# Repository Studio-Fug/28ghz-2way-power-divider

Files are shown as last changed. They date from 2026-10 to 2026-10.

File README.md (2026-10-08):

# 28 GHz two-way power divider / combiner

Experimental YAPNR inverse-designed microstrip Wilkinson coupon targeting the Knowles PDW07630's 24–32 GHz small-signal performance. **Revision A fails the return-loss and loss requirements in exported-footprint simulation. It is not a validated replacement for PDW07630.**

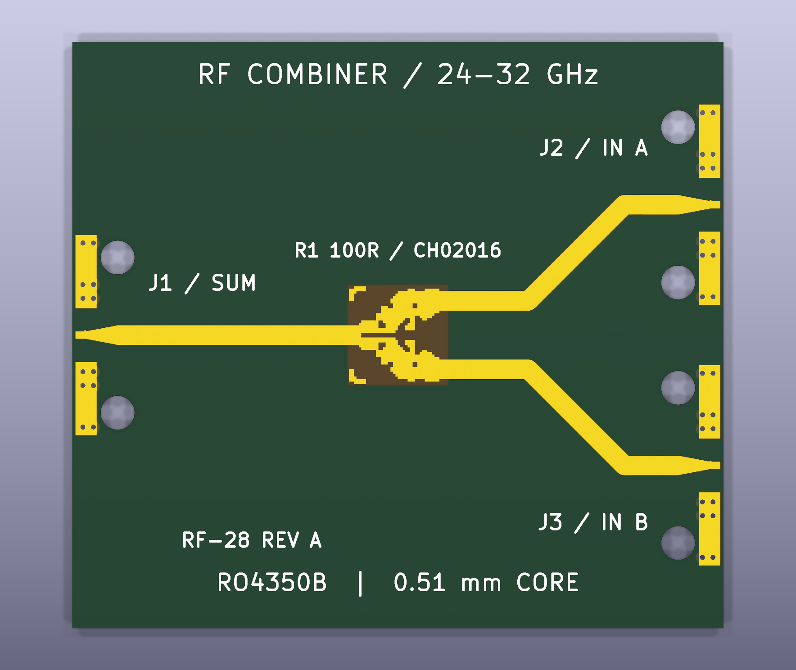
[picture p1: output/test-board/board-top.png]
Revision A test board, bare PCB with edge-launch footprints


The 40 × 36 mm board uses a 0.51 mm RO4350B core, three Southwest Microwave 1092-03A-6 2.92 mm edge launches, equal-length output feeds and a 100 ohm Vishay CH02016 resistor. J1 is SUM, J2/J3 are the two inputs/outputs. The board shot is a KiCad render of the actual copper and mechanical lands; connectors and resistor are not installed in the render.

- [Requirements model](requirements/model.yaml): 3 user needs, 15 requirements and 6 verification methods.
- [Validation report](reports/validation.md): acceptance criteria, grid comparison and links to simulation results.
- [rules_requirements traceability](reports/traceability.md), [HTML](reports/traceability.html), [JSON](reports/traceability.json), [gap queue](reports/gaps.json).
- [KiCad PCB](output/test-board/rf-combiner-test.kicad_pcb), [project](output/test-board/rf-combiner-test.kicad_pro), [BOM](output/test-board/BOM.csv).
- [Fabrication ZIP](output/test-board/rf-combiner-revA-fabrication.zip), [fabrication/assembly notes](FABRICATION.md). Layout DRC passes; RF acceptance does not.
- [Exported RF footprint](runs/jlc20mil/footprint.kicad_mod), [simulation metrics](runs/jlc20mil/comparison.json), [artifact hashes](reports/artifact-manifest.json).

## Requirements and sources

The baseline is the [Knowles datasheet](https://www.knowlescapacitors.com/getattachment/Products/Microwave-Products/Power-Dividers/PDW07630_DATASHEET.pdf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), preserved as [reference PDF](reference/PDW07630_DATASHEET.pdf): 24–32 GHz, return loss ≥15 dB, isolation ≥14 dB, excess insertion loss ≤0.7 dB, amplitude balance ±0.5 dB, phase balance ±5°. The combiner is specified for equal-amplitude, equal-phase inputs. Its 5 W combining rating is not qualified for this coupon.

The workflow follows [YAPNR RF inverse design](https://studio-fug.github.io/yapnr/docs/rf-inverse-design.html). The user's final stackup selection superseded the earlier 10 mil option: **0.51 mm core and 2.92 mm launches**. A larger board footprint was accepted. [DUT optimization spec](specs/dut-optimization.json) holds stricter optimization goals (20 dB return loss, 17 dB isolation, 0.5 dB excess loss); [requirements/model.yaml](requirements/model.yaml) retains the datasheet minimum acceptance thresholds.

## Whole-assembly validation gate

[spec.json](spec.json) is the authoritative project specification. It requires simulation of the complete populated assembly at the three 2.92 mm coaxial mating planes, including the actual feed bends, launch transitions, connectors, ground/vias, finite board, material losses and resistor package. All assembly RF limits include fixture losses. DUT-only simulation and DRC cannot satisfy this gate. One YAPNR-owned assembly SSoT must drive all backend adapters, with common geometry, materials, component mappings and reference planes; client projects supply declarative design/requirements data and must not write custom solver-model or mesh code.

**Assembly simulation is BLOCKED, not completed.** [Readiness report](reports/assembly-validation.json) records missing qualified connector/material models, resistor reference-plane qualification and a supported full-assembly SSoT/adapter workflow. YAPNR does provide suitable openEMS/PALACE engines and partial KiCad/mesh/config integration; the gap is the end-to-end minimal-code assembly path ([issue #97](https://github.com/Studio-Fug/yapnr/issues/97)). The [importer audit](reports/backend-capability-audit.json) also found omitted floating copper and NPTH geometry errors. A [Vishay 100 ohm candidate model](models/resistor/CH02016F_P_100R.s2p) is included, with [provenance](models/resistor/provenance.json); it has 100 ohm normalization and must be qualified before co-simulation.

Run `python3 scripts/check_assembly_readiness.py` to regenerate the readiness report. It intentionally returns a nonzero exit status until assembly simulation is possible, and never grants validation from readiness alone. REQ-13 through REQ-15 track complete-assembly RF acceptance, model coverage and numerical/tolerance evidence. REQ-11 remains the separate measured bench acceptance requirement.

## Reproduction

Docker is required for RF simulation. YAPNR is an external dependency, pinned by [upstream image digest, Git revision and archive checksum](dependencies/yapnr.json). The run scripts build a cached runtime image from [Dockerfile](Dockerfile), fetching upstream source during the build; no YAPNR source is vendored in this repository. The upstream image includes Torch 2.3.1 and the native FDTD backend, but its wheel omits `yapnr.rf.export` ([upstream issue #96](https://github.com/Studio-Fug/yapnr/issues/96)). Until that packaging defect is fixed, the derived image loads the complete pinned upstream Python package from `/opt/yapnr-dependency`, retaining the base image's matching native solver. This is a temporary source-dependency workaround, not a `pip install git+...` installation. Build-time imports and native-source checks fail if the dependency is incomplete or mismatched. Containers are bounded to two CPU cores and 6 GB RAM. The first build needs network access; later builds reuse Docker layers.

```sh
./run-container.sh > optimization.log 2>&1
./run-validation.sh > validation.log 2>&1
```

The committed run contains the checkpoint, optimization history, exported footprint, full complex S-parameter sweeps and mesh masks. Rerunning optimization resumes the checkpoint; move `runs/jlc20mil` aside first for a fresh run. Validation simulates the exported polygons on 0.15, 0.075 and 0.05 mm lateral grids with 4, 6 and 8 substrate cells. Each validation sweep has 81 frequencies from 24 to 32 GHz and 50 ohm reference impedance at the DUT boundary planes. The complete fixture is not included in that simulation.

To regenerate the requirements report with Python 3.9+:

```sh
python3 -m venv .venv
. .venv/bin/activate
pip install -r requirements/requirements.txt
./scripts/report.sh
```

`--fail-on none` permits report generation with known design failures; it does not change their verdicts. Each evidence case owns exactly one requirement. The verification lock pins the expected case sets; the evidence records simulation file paths and SHA-256 hashes.

Build the PCB using KiCad 10's `pcbnew` Python bindings, then run native DRC:

```sh
python3 build_board.py runs/jlc20mil/footprint.kicad_mod
kicad-cli pcb drc --exit-code-violations --format json \
  --output output/test-board/drc.json output/test-board/rf-combiner-test.kicad_pcb
```

The build converts the continuous multi-terminal footprint graphic to a custom-pad primitive without changing its polygon coordinates, enabling KiCad's connectivity checks. The three microwave port numbers share a DC net, as expected for a Wilkinson copper island.

## Timing

[timing.json](output/timing.json) records the available first-prompt timestamp, optimizer duration, completion of validation, and repository delivery. The first-prompt timestamp may have been replayed on restart; any earlier unrecorded interval is excluded. Completing a validation procedure does not mean the design passed validation.

## Third-party material

YAPNR is an external AGPL-3.0 dependency; its source and license are available in the [upstream repository](https://github.com/Studio-Fug/yapnr). Manufacturer documents retain their respective copyrights. Tool revisions and image digest are recorded in [dependencies/yapnr.json](dependencies/yapnr.json) and [result.json](runs/jlc20mil/result.json). The initial simulations used a local snapshot of the same revision. Every Python module was byte-compared with the fetched upstream source and matched, and the native source hash also matches; historical simulation artifacts are unchanged.

A plot of the recorded validation sweeps is in [simulation-comparison.png](reports/simulation-comparison.png); regenerate it with `python3 scripts/plot_results.py` after installing NumPy and Matplotlib.

To verify that the external dependency reproduces the original simulation, run:

```sh
./scripts/build-runtime.sh
docker run --rm --cpus 2 --memory 6g -v "$PWD:/project" -w /tmp \
  -e OPENBLAS_NUM_THREADS=1 -e OMP_NUM_THREADS=2 -e YAPNR_RF_THREADS=2 \
  -e YAPNR_RF_REQUIRE_NATIVE=1 --entrypoint python3 \
  28ghz-divider-rf:57df5897-1 -u /project/scripts/check_dependency.py
```

[Recorded dependency check](reports/dependency-smoke.json) compares the full complex coarse-grid S matrix, with exact equality required.

The [public Knowledge PoC](knowledge/README.md) packages requirements, simulation evidence and commit-pinned board artifacts into a signed object, preserving failed and missing validation.

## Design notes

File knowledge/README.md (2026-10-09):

# RF combiner public proof of concept

This version-2 Knowledge object represents the [experimental 28 GHz divider](https://github.com/Studio-Fug/28ghz-2way-power-divider) at commit `66c6e169a4a4493971753f8e23b1d327d4e11174`. It demonstrates requirements, evidence and Git-backed design records; it is not a passing or independently certified RF design.

The object contains 15 requirements and 10 publisher-reported evidence entries: seven pass, three fail, and five requirements have no completed evidence. DUT return loss and insertion/combining loss fail acceptance. Whole populated assembly simulation and physical/power qualification remain outstanding. Existing simulation results apply to the DUT window, not the connector mating planes. Inspection evidence uses the conservative `analysis` rigor category.

Three immutable Git sources commit the fabrication board, validation reports, and simulation results using Knowledge tree hashes. The reports reference the retained Touchstone/NPZ datasets. YAPNR remains an external dependency. Its missing whole-assembly SSoT/adapters are tracked in [YAPNR #97](https://github.com/Studio-Fug/yapnr/issues/97).

The signature uses a prototype publisher identity. It authenticates this translation, not an independently authenticated original simulation operator or the Studio-Fug organization. No private key is distributed. Knowledge verifies content, signatures and trace structure; realization does not rerun simulations.

Artifact address: `9cdb703565b6e97f87064670c3646c4d566506af4e155964fe5069bd6695b88e`.
Subject hash: `17c7899537adb3e669f6a502e5c591e4fbd789ab6886cb34bdcc026a1f7f00b6`.

Use `knowledge inspect --help`, `knowledge put --help`, and `knowledge realize --help` for CLI options. Inspect the artifact, insert it into a local cache, and search with incomplete results enabled. Default search excludes it. Realization requires explicitly allowing `https://codeload.github.com`; all three sources were successfully materialized and checked (1,731,964 bytes). The resulting status is `failed` and `reusable: false`.

The divider repository provides `scripts/export_knowledge_object.py` and `knowledge/source-commitments.json` to reproduce the payload. Generate a private prototype key locally and seal the payload with Knowledge; a new key changes the artifact address. Do not commit private keys. Regeneration should use the pinned design revision and its matching source commitments.

Local CLI receipts are retained in `inspect.json`, `search-default.json`, `search-incomplete.json` and `realization.json`. Materialized bundles are generated and excluded from Git.

The root `knowledge.json` is the import contract for knowledge-core. It identifies the signed artifact and its byte hash/address; requirements, specification, validation and source commitments remain owned by this project. Catalog entries pin a GitHub revision and import this descriptor. The part is cached, not contributed to the Knowledge implementation repository.

[knowledge-core](https://github.com/Studio-Fug/knowledge-core) now owns the pinned catalog entry and cache reconciliation tool. The original implementation-repo draft PR was closed. `cache-state.json` records the successful catalog import into the local `.knowledge` cache; a repeat import was also verified.

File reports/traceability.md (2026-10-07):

# 28 GHz two-way divider revision A

**0/3** user needs validated · **7/15** requirements verified (0 under-verified, 3 failed, 0 invalid, 3 incomplete, 2 unverified) · **0/0** risks mitigated · 27 test cases (27 owned, 0 unowned, 0 quarantined) · 8 gaps

_attribution: hybrid · lock: requirements/verification.rrlock_

## User needs — validation

| ID | Need | Requirements | Status |
|---|---|---|---|
| UN-1 | Comparable small-signal two-way 24-32 GHz combiner | REQ-1, REQ-2, REQ-3, REQ-4, REQ-5, REQ-6, REQ-11, REQ-12, REQ-13 | ❌ FAILED |
| UN-2 | JLC-compatible test coupon using 0.51 mm core and 2.92 mm launches | REQ-8, REQ-9, REQ-10, REQ-11, REQ-13, REQ-14 | 🟡 PARTIAL |
| UN-3 | Traceable design with reproducible simulation evidence | REQ-7, REQ-15 | 🟡 PARTIAL |

## Requirements — verification

| ID | Requirement | Traces | Demands | Evidence | Status |
|---|---|---|---|---|---|
| REQ-1 | DUT-plane: Return loss >=15 dB at each port over 24-32 GHz | satisfies UN-1 | simulation | set 0/3 passed · 3 failed<br>✗ rf_validation::coarse_REQ-1 [simulation]<br>✗ rf_validation::fine_REQ-1 [simulation]<br>✗ rf_validation::finer_REQ-1 [simulation] | ❌ FAILED |
| REQ-2 | DUT-plane: Isolation >=14 dB over 24-32 GHz | satisfies UN-1 | simulation | set 3/3 passed<br>✓ rf_validation::coarse_REQ-2 [simulation]<br>✓ rf_validation::fine_REQ-2 [simulation]<br>✓ rf_validation::finer_REQ-2 [simulation] | ✅ VERIFIED |
| REQ-3 | DUT-plane: Excess insertion loss <=0.7 dB in both directions over 24-32 GHz | satisfies UN-1 | simulation | set 0/3 passed · 3 failed<br>✗ rf_validation::coarse_REQ-3 [simulation]<br>✗ rf_validation::fine_REQ-3 [simulation]<br>✗ rf_validation::finer_REQ-3 [simulation] | ❌ FAILED |
| REQ-4 | DUT-plane: Amplitude imbalance <=0.5 dB over 24-32 GHz | satisfies UN-1 | simulation | set 3/3 passed<br>✓ rf_validation::coarse_REQ-4 [simulation]<br>✓ rf_validation::fine_REQ-4 [simulation]<br>✓ rf_validation::finer_REQ-4 [simulation] | ✅ VERIFIED |
| REQ-5 | DUT-plane: Phase imbalance <=5 degrees over 24-32 GHz | satisfies UN-1 | simulation | set 3/3 passed<br>✓ rf_validation::coarse_REQ-5 [simulation]<br>✓ rf_validation::fine_REQ-5 [simulation]<br>✓ rf_validation::finer_REQ-5 [simulation] | ✅ VERIFIED |
| REQ-6 | DUT-plane: Equal-phase coherent combining loss <=0.7 dB | satisfies UN-1 | simulation | set 0/3 passed · 3 failed<br>✗ rf_validation::coarse_REQ-6 [simulation]<br>✗ rf_validation::fine_REQ-6 [simulation]<br>✗ rf_validation::finer_REQ-6 [simulation] | ❌ FAILED |
| REQ-7 | DUT-plane: Scattering matrix is passive within 0.001 numerical tolerance | satisfies UN-3 | simulation | set 3/3 passed<br>✓ rf_validation::coarse_REQ-7 [simulation]<br>✓ rf_validation::fine_REQ-7 [simulation]<br>✓ rf_validation::finer_REQ-7 [simulation] | ✅ VERIFIED |
| REQ-8 | 40 x 36 mm two-layer RO4350B coupon with 0.51 mm core | satisfies UN-2 | inspection | set 1/1 passed<br>✓ rf_validation::core_and_outline [inspection] | ✅ VERIFIED |
| REQ-9 | Three 1092-03A-6 2.92 mm edge-launch footprints and microstrip feeds | satisfies UN-2 | inspection | set 1/1 passed<br>✓ rf_validation::launch_footprints [inspection] | ✅ VERIFIED |
| REQ-10 | Zero native KiCad DRC violations and unconnected items | satisfies UN-2 | inspection | set 1/1 passed<br>✓ rf_validation::native_drc [inspection] | ✅ VERIFIED |
| REQ-11 | Complete fixture meets RF limits at calibrated connector reference planes | satisfies UN-1, UN-2 | hil | — | ⚪ UNVERIFIED |
| REQ-12 | Qualify 5 W coherent combining under specified thermal conditions | satisfies UN-1 | hil | — | ⚪ UNVERIFIED |
| REQ-13 | Whole populated assembly meets every RF acceptance limit at the three coaxial connector planes | satisfies UN-1, UN-2 | simulation | set 0/1 passed · 1 skipped<br>– assembly_validation::full_assembly_rf_acceptance [simulation] | 🟡 INCOMPLETE |
| REQ-14 | Assembly model covers actual geometry, materials, contacts and package parasitics with qualified provenance | satisfies UN-2 | inspection | set 0/1 passed · 1 skipped<br>– assembly_validation::assembly_model_scope [inspection] | 🟡 INCOMPLETE |
| REQ-15 | Whole-assembly RF results have mesh, time-domain and tolerance convergence evidence | satisfies UN-3 | simulation | set 0/1 passed · 1 skipped<br>– assembly_validation::mesh_and_tolerance_convergence [simulation] | 🟡 INCOMPLETE |

## Test methods

| ID | Method | Level | Used by |
|---|---|---|---|
| TM-1 | Exported-footprint native FDTD on three grids | simulation | REQ-1, REQ-2, REQ-3, REQ-4, REQ-5, REQ-6, REQ-7 |
| TM-2 | KiCad native DRC and geometry inspection | inspection | REQ-8, REQ-9, REQ-10 |
| TM-3 | Calibrated three-port VNA measurement | hil | REQ-11 |
| TM-4 | Controlled-power thermal qualification | hil | REQ-12 |
| TM-5 | Complete assembly EM/co-simulation at coaxial connector planes | simulation | REQ-13, REQ-15 |
| TM-6 | Assembly model coverage and provenance inspection | inspection | REQ-14 |

## Verification sets

Each entity's set: the cases it owns, the cases it expects (literal selectors, the lock) and every quarantined case that names it. It is verified only when the whole set passed together.

### REQ-1 — ❌ FAILED

set 0/3 passed · 3 failed

| Case | State | Level | Via | Selector | Note |
|---|---|---|---|---|---|
| //:validation#rf_validation::coarse_REQ-1 | failed | simulation | model | rf_validation::coarse_REQ-1 |  |
| //:validation#rf_validation::fine_REQ-1 | failed | simulation | model | rf_validation::fine_REQ-1 |  |
| //:validation#rf_validation::finer_REQ-1 | failed | simulation | model | rf_validation::finer_REQ-1 |  |

### REQ-2 — ✅ VERIFIED

set 3/3 passed

| Case | State | Level | Via | Selector | Note |
|---|---|---|---|---|---|
| //:validation#rf_validation::coarse_REQ-2 | passed | simulation | model | rf_validation::coarse_REQ-2 |  |
| //:validation#rf_validation::fine_REQ-2 | passed | simulation | model | rf_validation::fine_REQ-2 |  |
| //:validation#rf_validation::finer_REQ-2 | passed | simulation | model | rf_validation::finer_REQ-2 |  |

### REQ-3 — ❌ FAILED

set 0/3 passed · 3 failed

| Case | State | Level | Via | Selector | Note |
|---|---|---|---|---|---|
| //:validation#rf_validation::coarse_REQ-3 | failed | simulation | model | rf_validation::coarse_REQ-3 |  |
| //:validation#rf_validation::fine_REQ-3 | failed | simulation | model | rf_validation::fine_REQ-3 |  |
| //:validation#rf_validation::finer_REQ-3 | failed | simulation | model | rf_validation::finer_REQ-3 |  |

### REQ-4 — ✅ VERIFIED

set 3/3 passed

| Case | State | Level | Via | Selector | Note |
|---|---|---|---|---|---|
| //:validation#rf_validation::coarse_REQ-4 | passed | simulation | model | rf_validation::coarse_REQ-4 |  |
| //:validation#rf_validation::fine_REQ-4 | passed | simulation | model | rf_validation::fine_REQ-4 |  |
| //:validation#rf_validation::finer_REQ-4 | passed | simulation | model | rf_validation::finer_REQ-4 |  |

### REQ-5 — ✅ VERIFIED

set 3/3 passed

| Case | State | Level | Via | Selector | Note |
|---|---|---|---|---|---|
| //:validation#rf_validation::coarse_REQ-5 | passed | simulation | model | rf_validation::coarse_REQ-5 |  |
| //:validation#rf_validation::fine_REQ-5 | passed | simulation | model | rf_validation::fine_REQ-5 |  |
| //:validation#rf_validation::finer_REQ-5 | passed | simulation | model | rf_validation::finer_REQ-5 |  |

### REQ-6 — ❌ FAILED

set 0/3 passed · 3 failed

| Case | State | Level | Via | Selector | Note |
|---|---|---|---|---|---|
| //:validation#rf_validation::coarse_REQ-6 | failed | simulation | model | rf_validation::coarse_REQ-6 |  |
| //:validation#rf_validation::fine_REQ-6 | failed | simulation | model | rf_validation::fine_REQ-6 |  |
| //:validation#rf_validation::finer_REQ-6 | failed | simulation | model | rf_validation::finer_REQ-6 |  |

### REQ-7 — ✅ VERIFIED

set 3/3 passed

| Case | State | Level | Via | Selector | Note |
|---|---|---|---|---|---|
| //:validation#rf_validation::coarse_REQ-7 | passed | simulation | model | rf_validation::coarse_REQ-7 |  |
| //:validation#rf_validation::fine_REQ-7 | passed | simulation | model | rf_validation::fine_REQ-7 |  |
| //:validation#rf_validation::finer_REQ-7 | passed | simulation | model | rf_validation::finer_REQ-7 |  |

### REQ-8 — ✅ VERIFIED

set 1/1 passed

| Case | State | Level | Via | Selector | Note |
|---|---|---|---|---|---|
| //:validation#rf_validation::core_and_outline | passed | inspection | model | rf_validation::core_and_outline |  |

### REQ-9 — ✅ VERIFIED

set 1/1 passed

| Case | State | Level | Via | Selector | Note |
|---|---|---|---|---|---|
| //:validation#rf_validation::launch_footprints | passed | inspection | model | rf_validation::launch_footprints |  |

### REQ-10 — ✅ VERIFIED

set 1/1 passed

| Case | State | Level | Via | Selector | Note |
|---|---|---|---|---|---|
| //:validation#rf_validation::native_drc | passed | inspection | model | rf_validation::native_drc |  |

### REQ-13 — 🟡 INCOMPLETE

set 0/1 passed · 1 skipped

| Case | State | Level | Via | Selector | Note |
|---|---|---|---|---|---|
| //:validation#assembly_validation::full_assembly_rf_acceptance | skipped | simulation | model | assembly_validation::full_assembly_rf_acceptance |  |

### REQ-14 — 🟡 INCOMPLETE

set 0/1 passed · 1 skipped

| Case | State | Level | Via | Selector | Note |
|---|---|---|---|---|---|
| //:validation#assembly_validation::assembly_model_scope | skipped | inspection | model | assembly_validation::assembly_model_scope |  |

### REQ-15 — 🟡 INCOMPLETE

set 0/1 passed · 1 skipped

| Case | State | Level | Via | Selector | Note |
|---|---|---|---|---|---|
| //:validation#assembly_validation::mesh_and_tolerance_convergence | skipped | simulation | model | assembly_validation::mesh_and_tolerance_convergence |  |

## Case attribution

| Target | Cases | Owned | Quarantined | Unowned | Owners |
|---|---|---|---|---|---|
| //:validation | 27 | 27 | 0 | 0 | REQ-1, REQ-2, REQ-3, REQ-4, REQ-5, REQ-6, REQ-7, REQ-8, REQ-9, REQ-10, REQ-13, REQ-14, REQ-15 |

## Gaps

| Kind | Entity | Route | Detail |
|---|---|---|---|
| failed | REQ-1 | autonomous | failing evidence: rf_validation::coarse_REQ-1, rf_validation::fine_REQ-1, rf_validation::finer_REQ-1 |
| failed | REQ-3 | autonomous | failing evidence: rf_validation::coarse_REQ-3, rf_validation::fine_REQ-3, rf_validation::finer_REQ-3 |
| failed | REQ-6 | autonomous | failing evidence: rf_validation::coarse_REQ-6, rf_validation::fine_REQ-6, rf_validation::finer_REQ-6 |
| unverified | REQ-11 | human-gate | no test evidence |
| unverified | REQ-12 | human-gate | no test evidence |
| incomplete | REQ-13 | autonomous | 0/1 passed; 1 skipped (//:validation) |
| incomplete | REQ-14 | human-gate | 0/1 passed; 1 skipped (//:validation) |
| incomplete | REQ-15 | autonomous | 0/1 passed; 1 skipped (//:validation) |

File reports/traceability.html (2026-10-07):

# 28 GHz two-way divider revision A

attribution: hybrid · lock: requirements/verification.rrlock

0/3

user needs validated

7/15

requirements verified

0/0

mitigations verified

0/0

risks mitigated

## Trace graph

## User needs — validation

ID | Need | Requirements | Status
UN-1 | Comparable small-signal two-way 24-32 GHz combiner | REQ-1, REQ-2, REQ-3, REQ-4, REQ-5, REQ-6, REQ-11, REQ-12, REQ-13 | FAILED
UN-2 | JLC-compatible test coupon using 0.51 mm core and 2.92 mm launches | REQ-8, REQ-9, REQ-10, REQ-11, REQ-13, REQ-14 | PARTIAL
UN-3 | Traceable design with reproducible simulation evidence | REQ-7, REQ-15 | PARTIAL

## Requirements — verification

ID | Requirement | Evidence | Status
REQ-1 | DUT-plane: Return loss >=15 dB at each port over 24-32 GHz Simulation-only acceptance. Physical equivalence requires REQ-11. satisfies UN-1 | set 0/3 passed · 3 failed

Case | State | Level | Via | Note
//:validation#rf_validation::coarse_REQ-1 | failed | simulation | model rf_validation::coarse_REQ-1
//:validation#rf_validation::fine_REQ-1 | failed | simulation | model rf_validation::fine_REQ-1
//:validation#rf_validation::finer_REQ-1 | failed | simulation | model rf_validation::finer_REQ-1

- rf_validation::coarse_REQ-1 //:validation simulation
  minimum per-port return loss: [12.643721220497714, 14.610223022129599, 14.610223022130008]; source=runs/jlc20mil/coarse-validated.s3p; sha256=f11c4239d8909421c101154086765d16ad95f2e6bd1d37ac2aa975fa72bde8dd; metrics=runs/jlc20mil/comparison.json#/grids/coarse/return_loss_min_db_per_port
- rf_validation::fine_REQ-1 //:validation simulation
  minimum per-port return loss: [11.929100539083946, 14.13139508009607, 14.13139508009522]; source=runs/jlc20mil/fine-validated.s3p; sha256=499c4270f55929fdd5a970f2c6fb168cb9a54e8287a437c29eef349f024c95cd; metrics=runs/jlc20mil/comparison.json#/grids/fine/return_loss_min_db_per_port
- rf_validation::finer_REQ-1 //:validation simulation
  minimum per-port return loss: [11.822555861296191, 14.020467339715182, 14.020467339710052]; source=runs/jlc20mil/finer-validated.s3p; sha256=c39cd5836ad59bd78b036d1563f77ae30dc24d01476cac07fd4eebc8f1706f3f; metrics=runs/jlc20mil/comparison.json#/grids/finer/return_loss_min_db_per_port

demands simulation via TM-1

FAILED
REQ-2 | DUT-plane: Isolation >=14 dB over 24-32 GHz Simulation-only acceptance. Physical equivalence requires REQ-11. satisfies UN-1 | set 3/3 passed

Case | State | Level | Via | Note
//:validation#rf_validation::coarse_REQ-2 | passed | simulation | model rf_validation::coarse_REQ-2
//:validation#rf_validation::fine_REQ-2 | passed | simulation | model rf_validation::fine_REQ-2
//:validation#rf_validation::finer_REQ-2 | passed | simulation | model rf_validation::finer_REQ-2

- rf_validation::coarse_REQ-2 //:validation simulation
- rf_validation::fine_REQ-2 //:validation simulation
- rf_validation::finer_REQ-2 //:validation simulation

demands simulation via TM-1 · best simulation

VERIFIED
REQ-3 | DUT-plane: Excess insertion loss <=0.7 dB in both directions over 24-32 GHz Simulation-only acceptance. Physical equivalence requires REQ-11. satisfies UN-1 | set 0/3 passed · 3 failed

Case | State | Level | Via | Note
//:validation#rf_validation::coarse_REQ-3 | failed | simulation | model rf_validation::coarse_REQ-3
//:validation#rf_validation::fine_REQ-3 | failed | simulation | model rf_validation::fine_REQ-3
//:validation#rf_validation::finer_REQ-3 | failed | simulation | model rf_validation::finer_REQ-3

- rf_validation::coarse_REQ-3 //:validation simulation
  maximum excess loss: 0.7957604625884325; source=runs/jlc20mil/coarse-validated.s3p; sha256=f11c4239d8909421c101154086765d16ad95f2e6bd1d37ac2aa975fa72bde8dd; metrics=runs/jlc20mil/comparison.json#/grids/coarse/excess_loss_max_db
- rf_validation::fine_REQ-3 //:validation simulation
  maximum excess loss: 0.845783048462776; source=runs/jlc20mil/fine-validated.s3p; sha256=499c4270f55929fdd5a970f2c6fb168cb9a54e8287a437c29eef349f024c95cd; metrics=runs/jlc20mil/comparison.json#/grids/fine/excess_loss_max_db
- rf_validation::finer_REQ-3 //:validation simulation
  maximum excess loss: 0.86237582756605; source=runs/jlc20mil/finer-validated.s3p; sha256=c39cd5836ad59bd78b036d1563f77ae30dc24d01476cac07fd4eebc8f1706f3f; metrics=runs/jlc20mil/comparison.json#/grids/finer/excess_loss_max_db

demands simulation via TM-1

FAILED
REQ-4 | DUT-plane: Amplitude imbalance <=0.5 dB over 24-32 GHz Simulation-only acceptance. Physical equivalence requires REQ-11. satisfies UN-1 | set 3/3 passed

Case | State | Level | Via | Note
//:validation#rf_validation::coarse_REQ-4 | passed | simulation | model rf_validation::coarse_REQ-4
//:validation#rf_validation::fine_REQ-4 | passed | simulation | model rf_validation::fine_REQ-4
//:validation#rf_validation::finer_REQ-4 | passed | simulation | model rf_validation::finer_REQ-4

- rf_validation::coarse_REQ-4 //:validation simulation
- rf_validation::fine_REQ-4 //:validation simulation
- rf_validation::finer_REQ-4 //:validation simulation

demands simulation via TM-1 · best simulation

VERIFIED
REQ-5 | DUT-plane: Phase imbalance <=5 degrees over 24-32 GHz Simulation-only acceptance. Physical equivalence requires REQ-11. satisfies UN-1 | set 3/3 passed

Case | State | Level | Via | Note
//:validation#rf_validation::coarse_REQ-5 | passed | simulation | model rf_validation::coarse_REQ-5
//:validation#rf_validation::fine_REQ-5 | passed | simulation | model rf_validation::fine_REQ-5
//:validation#rf_validation::finer_REQ-5 | passed | simulation | model rf_validation::finer_REQ-5

- rf_validation::coarse_REQ-5 //:validation simulation
- rf_validation::fine_REQ-5 //:validation simulation
- rf_validation::finer_REQ-5 //:validation simulation

demands simulation via TM-1 · best simulation

VERIFIED
REQ-6 | DUT-plane: Equal-phase coherent combining loss <=0.7 dB Simulation-only acceptance. Physical equivalence requires REQ-11. satisfies UN-1 | set 0/3 passed · 3 failed

Case | State | Level | Via | Note
//:validation#rf_validation::coarse_REQ-6 | failed | simulation | model rf_validation::coarse_REQ-6
//:validation#rf_validation::fine_REQ-6 | failed | simulation | model rf_validation::fine_REQ-6
//:validation#rf_validation::finer_REQ-6 | failed | simulation | model rf_validation::finer_REQ-6

- rf_validation::coarse_REQ-6 //:validation simulation
  maximum coherent loss: 0.7691722179703759; source=runs/jlc20mil/coarse-validated.s3p; sha256=f11c4239d8909421c101154086765d16ad95f2e6bd1d37ac2aa975fa72bde8dd; metrics=runs/jlc20mil/comparison.json#/grids/coarse/coherent_combining_loss_max_db
- rf_validation::fine_REQ-6 //:validation simulation
  maximum coherent loss: 0.8195787944013638; source=runs/jlc20mil/fine-validated.s3p; sha256=499c4270f55929fdd5a970f2c6fb168cb9a54e8287a437c29eef349f024c95cd; metrics=runs/jlc20mil/comparison.json#/grids/fine/coherent_combining_loss_max_db
- rf_validation::finer_REQ-6 //:validation simulation
  maximum coherent loss: 0.838400833755864; source=runs/jlc20mil/finer-validated.s3p; sha256=c39cd5836ad59bd78b036d1563f77ae30dc24d01476cac07fd4eebc8f1706f3f; metrics=runs/jlc20mil/comparison.json#/grids/finer/coherent_combining_loss_max_db

demands simulation via TM-1

FAILED
REQ-7 | DUT-plane: Scattering matrix is passive within 0.001 numerical tolerance Simulation-only acceptance. Physical equivalence requires REQ-11. satisfies UN-3 | set 3/3 passed

Case | State | Level | Via | Note
//:validation#rf_validation::coarse_REQ-7 | passed | simulation | model rf_validation::coarse_REQ-7
//:validation#rf_validation::fine_REQ-7 | passed | simulation | model rf_validation::fine_REQ-7
//:validation#rf_validation::finer_REQ-7 | passed | simulation | model rf_validation::finer_REQ-7

- rf_validation::coarse_REQ-7 //:validation simulation
- rf_validation::fine_REQ-7 //:validation simulation
- rf_validation::finer_REQ-7 //:validation simulation

demands simulation via TM-1 · best simulation

VERIFIED
REQ-8 | 40 x 36 mm two-layer RO4350B coupon with 0.51 mm core satisfies UN-2 | set 1/1 passed

Case | State | Level | Via | Note
//:validation#rf_validation::core_and_outline | passed | inspection | model rf_validation::core_and_outline

- rf_validation::core_and_outline //:validation inspection

demands inspection via TM-2 · best inspection

VERIFIED
REQ-9 | Three 1092-03A-6 2.92 mm edge-launch footprints and microstrip feeds satisfies UN-2 | set 1/1 passed

Case | State | Level | Via | Note
//:validation#rf_validation::launch_footprints | passed | inspection | model rf_validation::launch_footprints

- rf_validation::launch_footprints //:validation inspection

demands inspection via TM-2 · best inspection

VERIFIED
REQ-10 | Zero native KiCad DRC violations and unconnected items satisfies UN-2 | set 1/1 passed

Case | State | Level | Via | Note
//:validation#rf_validation::native_drc | passed | inspection | model rf_validation::native_drc

- rf_validation::native_drc //:validation inspection

demands inspection via TM-2 · best inspection

VERIFIED
REQ-11 | Complete fixture meets RF limits at calibrated connector reference planes Not simulated or measured: launches, feeds, packaged resistor, finish and tolerances require bench verification. satisfies UN-1, UN-2 | no evidence demands hil via TM-3 | UNVERIFIED
REQ-12 | Qualify 5 W coherent combining under specified thermal conditions No power or thermal qualification. Present resistor is intended for small-signal VNA tests only. satisfies UN-1 | no evidence demands hil via TM-4 | UNVERIFIED
REQ-13 | Whole populated assembly meets every RF acceptance limit at the three coaxial connector planes Mandatory release gate in spec.json assembly_validation. Include fixture losses and actual feeds/bends, launches, finite board, ground/vias and packaged resistor. DUT-only results do not satisfy this requirement. satisfies UN-1, UN-2 | set 0/1 passed · 1 skipped

Case | State | Level | Via | Note
//:validation#assembly_validation::full_assembly_rf_acceptance | skipped | simulation | model assembly_validation::full_assembly_rf_acceptance

- assembly_validation::full_assembly_rf_acceptance //:validation simulation

demands simulation via TM-5

INCOMPLETE
REQ-14 | Assembly model covers actual geometry, materials, contacts and package parasitics with qualified provenance Include every required_model_scope item in spec.json using the unified_model_contract: YAPNR-owned SSoT, part resolution and solver adapters; no bespoke client geometry/mesh/model-generation code. Missing or idealized models block assembly validation. satisfies UN-2 | set 0/1 passed · 1 skipped

Case | State | Level | Via | Note
//:validation#assembly_validation::assembly_model_scope | skipped | inspection | model assembly_validation::assembly_model_scope

- assembly_validation::assembly_model_scope //:validation inspection

demands inspection via TM-6

INCOMPLETE
REQ-15 | Whole-assembly RF results have mesh, time-domain and tolerance convergence evidence Three meshes, configured finest-pair error bounds, converged excitations, numerical checks and vendor-supported tolerance cases required by spec.json. satisfies UN-3 | set 0/1 passed · 1 skipped

Case | State | Level | Via | Note
//:validation#assembly_validation::mesh_and_tolerance_convergence | skipped | simulation | model assembly_validation::mesh_and_tolerance_convergence

- assembly_validation::mesh_and_tolerance_convergence //:validation simulation

demands simulation via TM-5

INCOMPLETE

## Test methods

ID | Method | Level | Used by
TM-1 | Exported-footprint native FDTD on three grids 81 frequencies from 24 to 32 GHz; 50 ohm renormalization; inspect reports/validation.md for limitations. | simulation | REQ-1, REQ-2, REQ-3, REQ-4, REQ-5, REQ-6, REQ-7
TM-2 | KiCad native DRC and geometry inspection | inspection | REQ-8, REQ-9, REQ-10
TM-3 | Calibrated three-port VNA measurement | hil | REQ-11
TM-4 | Controlled-power thermal qualification | hil | REQ-12
TM-5 | Complete assembly EM/co-simulation at coaxial connector planes | simulation | REQ-13, REQ-15
TM-6 | Assembly model coverage and provenance inspection | inspection | REQ-14

## Case attribution

Target | Cases | Owned | Quarantined | Unowned | Owners
//:validation | 27 | 27 | 0 | 0 | REQ-1, REQ-2, REQ-3, REQ-4, REQ-5, REQ-6, REQ-7, REQ-8, REQ-9, REQ-10, REQ-13, REQ-14, REQ-15

## Gaps — work queue

Kind | Entity | Route | Detail
failed | REQ-1 | autonomous | failing evidence: rf_validation::coarse_REQ-1, rf_validation::fine_REQ-1, rf_validation::finer_REQ-1
failed | REQ-3 | autonomous | failing evidence: rf_validation::coarse_REQ-3, rf_validation::fine_REQ-3, rf_validation::finer_REQ-3
failed | REQ-6 | autonomous | failing evidence: rf_validation::coarse_REQ-6, rf_validation::fine_REQ-6, rf_validation::finer_REQ-6
unverified | REQ-11 | human-gate | no test evidence
unverified | REQ-12 | human-gate | no test evidence
incomplete | REQ-13 | autonomous | 0/1 passed; 1 skipped (//:validation)
incomplete | REQ-14 | human-gate | 0/1 passed; 1 skipped (//:validation)
incomplete | REQ-15 | autonomous | 0/1 passed; 1 skipped (//:validation)

27 test cases (27 owned, 0 unowned, 0 quarantined; each case verifies at most one requirement) test cases · 8 gaps · generated by rules_requirements

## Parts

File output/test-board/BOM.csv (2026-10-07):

Reference | Qty | Value | Manufacturer | Part | Assembly
J1 J2 J3 | 3 | 2.92mm 40GHz edge launch | Southwest Microwave | 1092-03A-6 | Manual clamp installation
R1 | 1 | 100 ohm 70GHz thin-film resistor | Vishay Sfernice | CH02016-100RGFTF | Manual active face down; pads 4 and 5 of RF1

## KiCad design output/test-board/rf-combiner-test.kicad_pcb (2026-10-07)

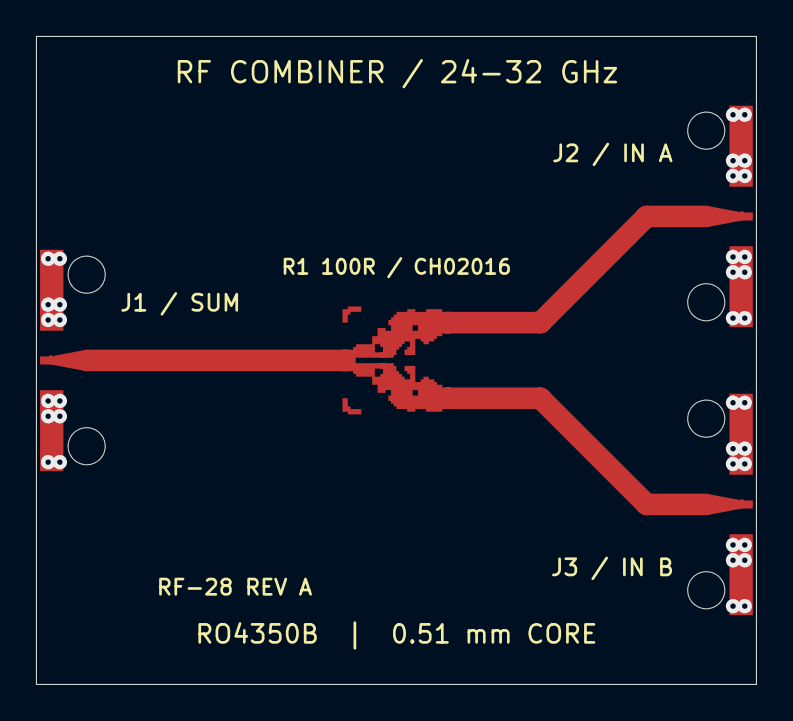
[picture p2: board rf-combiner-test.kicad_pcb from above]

Board: 2 copper layers, 40.0 x 36.0 mm, 7 parts (0 on the bottom side), 2 nets.

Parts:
J1: 1092-03A-6; SWM_1092-03A-6_Left
J2, J3: 1092-03A-6; SWM_1092-03A-6_Right
RF1: RF_pdw07630-comparable-jlc-ro4350b-20mil; footprint
TP1, TP2, TP3: (no value)

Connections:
GND: J1.2, J1.3, J2.2, J2.3, J3.2, J3.3
RF: J1.1, J2.1, J3.1, RF1.1, RF1.2, RF1.3, RF1.4, RF1.5, TP1.1, TP2.1, TP3.1

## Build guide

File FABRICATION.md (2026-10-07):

# Fabrication and assembly — experimental revision A

The Gerber/drill ZIP represents the committed 40 × 36 mm board. It has native KiCad DRC approval but **fails RF requirements**. Use it as a small-signal experimental coupon, not a production-equivalent combiner. Complete populated-assembly simulation at connector reference planes is mandatory under [spec.json](spec.json), and currently blocked; see [assembly status](reports/assembly-validation.json).

## JLC quote selections

| Item | Selection |
|---|---|
| Layers | 2 |
| Laminate | Rogers RO4350B |
| Core | 0.51 mm |
| Nominal finished thickness | JLC 0.65 mm option; confirm actual stackup |
| Copper | Nominal 1 oz, 35 µm |
| Finish | ENIG |
| Mask / legend | Green / white |
| Outline | 40 × 36 mm |
| Via | 0.30 mm plated drill / 0.80 mm copper diameter |
| Connector mounting holes | 2.06 mm NPTH, 9.53 mm spacing, 2.79 mm edge setback |

The explicit modeled copper/core thickness sum is 0.58 mm (35 + 510 + 35 µm). The nominal 0.65 mm finished-board selection is a vendor option, not a claim that 70 µm of finish has been modeled. Confirm the supplied dielectric core remains 0.51 mm and review JLC's finished stackup before ordering. Copper roughness and ENIG loss are not simulated.

Published fabrication sources: [JLC RF PCB service](https://jlcpcb.com/pcb-fabrication/high-frequency-pcb), [core options](https://jlcpcb.com/news/rogers-ptfe-high-frequency-pcb-available). Manufacturer mechanical drawing: [1092-03A-6](reference/1092-03A-6.pdf). RF microstrip and DUT copper are mask-open. The backside ground is continuous except for mechanical-hole clearances.

## Manual assembly and test

Install three Southwest Microwave 1092-03A-6 end launches. Their 2.92 mm interface is specified to 40 GHz; the planar launch transition on this coupon is not manufacturer RF-qualified. Check the connector block, pin contact and clamp seating against the board thickness before assembly.

Install Vishay CH02016-100RGFTF, 100 ohm, active face down across RF1 pads 4/5. The CAD pad geometry is inherited from the simulation's lumped resistor; verify the specific part termination overlap and solder process under magnification. The part has no packaged-resistor EM model in this run. See [CH datasheet](reference/ch.pdf). Do not substitute a generic 0201 resistor and assume identical RF behavior.

Begin with low-power VNA measurements (e.g. ≤0 dBm), measure all three ports, and account for the launch/feed sections when comparing DUT-plane results. There is no thermal or 5 W qualification, assembly service order or vendor upload in this repository. BOM lists manual components; no automated placement file is provided.

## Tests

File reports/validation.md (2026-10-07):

# Validation of revision A

**Overall disposition: FAIL — experimental small-signal coupon; PDW07630 equivalence is not established.**

**Whole-assembly validation is BLOCKED and has not run.** See [assembly status](assembly-validation.json) and the mandatory [project spec](../spec.json). DUT-only results cannot release the populated board.

The numerical results below assess only the exported DUT copper, not the populated assembly or only the optimizer's density model. Its results supersede the earlier optimizer summary. The reference planes are the three design-window boundaries, with 50 ohm renormalization, not the fixture connectors. Each sweep has 81 points over 24–32 GHz.

| Grid | Pitch mm | Worst return loss dB (>=15) | Isolation dB (>=14) | Excess loss dB (<=0.7) | Coherent combining loss dB (<=0.7) | Result |
|---|---:|---:|---:|---:|---:|---|
| coarse | 0.150 | 12.644 | 14.901 | 0.796 | 0.769 | FAIL |
| fine | 0.075 | 11.929 | 14.890 | 0.846 | 0.820 | FAIL |
| finer | 0.050 | 11.823 | 14.875 | 0.862 | 0.838 | FAIL |

The grid-by-grid data and individual-port metrics are in [comparison.json](../runs/jlc20mil/comparison.json). Raw simulation results: [coarse Touchstone](../runs/jlc20mil/coarse-validated.s3p), [fine Touchstone](../runs/jlc20mil/fine-validated.s3p), [finer Touchstone](../runs/jlc20mil/finer-validated.s3p). The corresponding NPZ files preserve complex S matrices, frequencies and rasterized copper. [Validation log](../validation.log) records mesh runtimes and backend. [validate_design.py](../validate_design.py) defines the procedure and acceptance thresholds. [Evidence XML](testlogs/validation/test.xml) references each simulation file by path and SHA-256, with one requirement per case.

Return loss and excess loss fail on the completed grids. Isolation, amplitude balance, phase balance and passivity pass. Mirror symmetry enforces nearly exact balance in this ideal model; it does not establish manufactured balance. Grid refinement is sensitivity evidence, not an assertion that the simulation is converged or matches hardware.

The optimizer used more demanding targets (20 dB return loss, 17 dB isolation, 0.5 dB excess loss) and did not meet them. It completed 73 iterations and mechanically selected iteration 25. See [optimizer result](../runs/jlc20mil/result.json), [history](../runs/jlc20mil/history.json) and [optimization log](../optimization.log). Its internal response differs from exported-polygon re-simulation; no claim is made that the export preserves the internal model's electrical response.

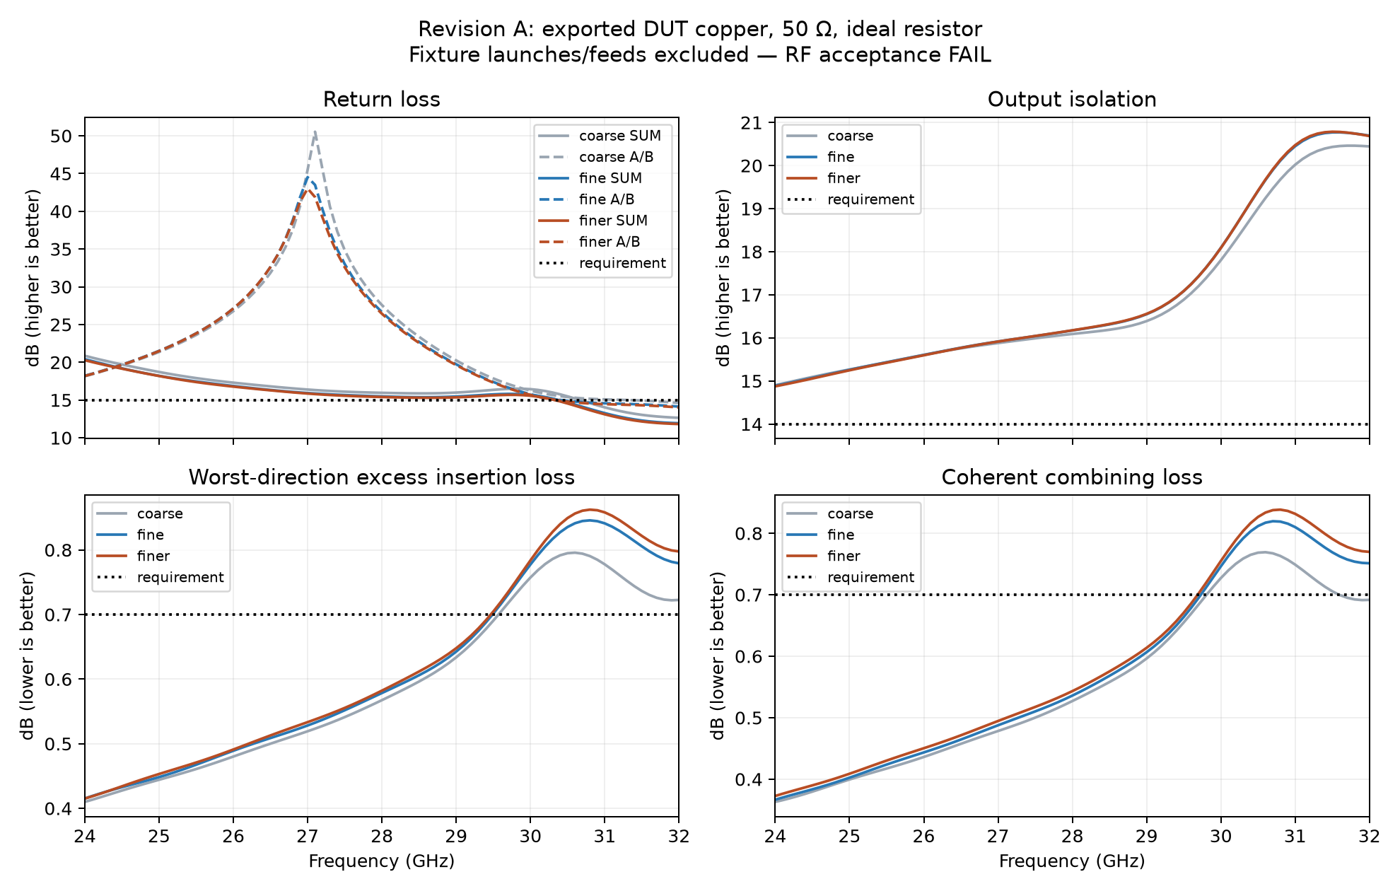
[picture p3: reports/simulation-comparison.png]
Grid comparison


## Dependency reproducibility

YAPNR is fetched as a pinned external dependency ([declaration](../dependencies/yapnr.json), [Dockerfile](../Dockerfile)). The original image omits RF export modules; [upstream issue #96](https://github.com/Studio-Fug/yapnr/issues/96) tracks the packaging fix. [Dependency smoke check](dependency-smoke.json) re-runs the coarse sweep outside the source checkout and compares its complex S matrix with the original committed simulation. The simulation artifacts and RF acceptance failures are unchanged.

## Assembly solver integration

YAPNR provides suitable openEMS and PALACE engines and partial integration, including a planar KiCad importer and the PALACE mesh/config/sign-off pipeline. The [backend audit](backend-capability-audit.json) found that this importer omits both floating copper islands (0.945 mm² total) and represents the NPTH pads as copper. No whole-assembly solve was performed. [Upstream issue #97](https://github.com/Studio-Fug/yapnr/issues/97) requests a unified assembly SSoT, YAPNR-owned component-model resolution and adapters, import coverage checks, and a minimal-code external validation workflow. The project [spec](../spec.json) explicitly requires this architecture; the client must not compensate with custom solver geometry or mesh scripts.

## Board verification

[Native KiCad 10.0.6 DRC](../output/test-board/drc.json): zero violations and zero unconnected items. This verifies layout rules and DC connectivity, not microwave performance. The main footprint polygon is represented as a custom-pad primitive in the board so it participates in KiCad connectivity; its polygon coordinates are preserved (verified by [exact coordinate comparison](board-geometry.json), including floating islands). [Board builder](../build_board.py) records this conversion. The optimized footprint's own minimum-width/space check is in result.json under drc.

## Limitations and outstanding validation

- Ideal 100 ohm lumped resistor; no CH02016 package or solder parasitics.
- Zero-thickness smooth copper sheet; no ENIG, copper roughness, plating variation or manufacturing tolerance model.
- Infinite substrate and ground approximation; fixture traces, connector launches, mounting holes and board edges are excluded from RF simulation.
- No measured S parameters, calibrated fixture de-embedding, power handling or thermal qualification. The 5 W combining rating of the reference part is not established for this coupon.
- JLC material availability and finished stackup must be confirmed when quoting. Connector mounting and resistor land compatibility require assembly review.

The rules_requirements [traceability report](traceability.md), [machine report](traceability.json), [HTML report](traceability.html) and [gap queue](gaps.json) preserve failures and unverified bench requirements. Passing simulation evidence has simulation rigor only; it does not verify the complete fixture.

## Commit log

2026-10-07 Add experimental 28 GHz combiner board and simulation-linked validation
    Include the 0.51 mm RO4350B coupon, 2.92 mm launch footprints, fabrication files, and reproducible YAPNR runs. Trace requirements through locked rules_requirements evidence; record failed RF acceptance and unverified bench/power qualification.
    [BOM.csv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]
2026-10-07 Require full populated-assembly simulation in the project specification
    Define coaxial connector-plane RF acceptance including feeds, bends, launches, finite board, ground/vias, material losses and resistor parasitics. Preserve the original DUT optimization input separat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
2026-10-07 Require YAPNR-owned assembly SSoT and backend adapters
    Recognize the existing openEMS/PALACE integrations and track the minimal-code full-assembly workflow in Studio-Fug/yapnr#97. Record concrete KiCad import coverage defects and keep assembly validation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
